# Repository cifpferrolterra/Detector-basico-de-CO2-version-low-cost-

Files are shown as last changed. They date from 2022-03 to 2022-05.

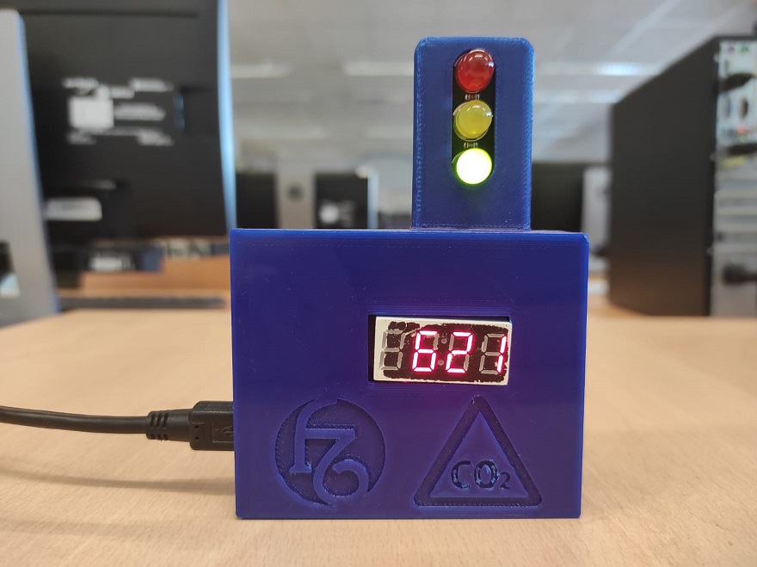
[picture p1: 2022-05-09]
Vista frontal detector low cost.jpg

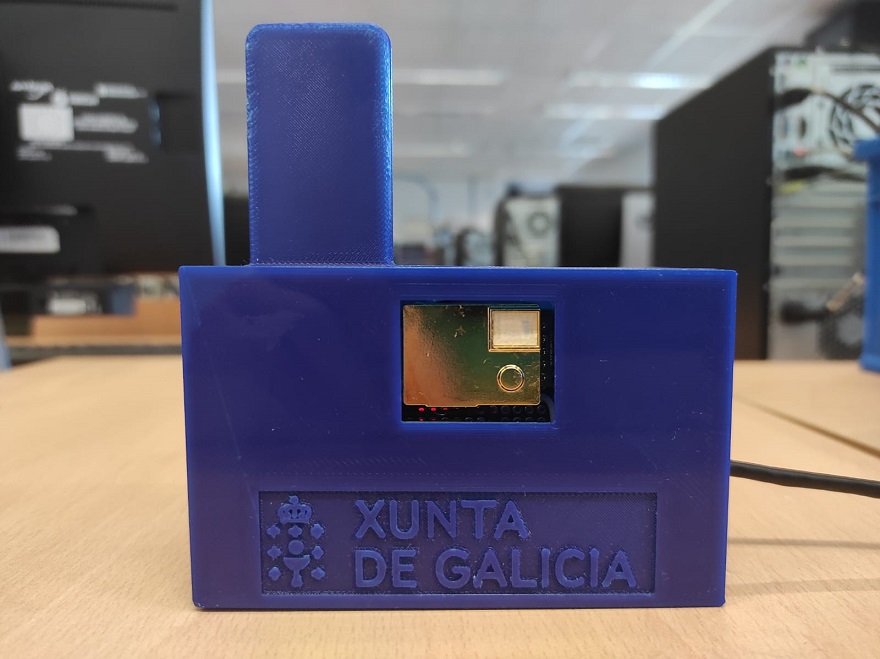
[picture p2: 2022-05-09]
Vista trasera detector low cost.jpg

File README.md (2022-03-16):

# Detector-basico-de-CO2-version-low-cost-
Aulas saudables no CIFP Ferrolterra

A situación de pandemia motivada pola COVID-19 está a xerar a necesidade de ventilar os espazos cunha frecuencia maior do que se facía ata o de agora. Isto débese a que investigadores determinaron que existe unha relación entre os niveis de CO2 e o virus, xa que, se o CO2 está concentrado, o virus estará tamén concentrado exactamente igual, incrementándose a probabilidade de contaxio.
A concentración de CO2 en espazos interiores cerrados aumenta rapidamente na presenza de persoas, que exhalan CO2 ao respirar. A renovación do aire co aire exterior reduce as concentracións de CO2 no interior. Para optimizar esta necesidade de ventilación están a xurdir distintos aparellos de detección de CO2, moitos deles de baixo custo ou low cost. A problemática dalgúns destes últimos é que non fan unha medición real do CO2, senón unha estimación ou prorrateo en función da medición doutros parámetros.
A idea do proxecto “Aulas saudables no CIFP Ferrolterra” xurde da necesidade de ventilación motivada pola pandemia da COVID-19 no noso centro, e da de dispoñer dun sistema de baixo custo que permita contar cunha unidade de detección por aula: ao tratarse dun centro tan grande, unhas 50. A posibilidade de que sexa construíble, programable e reparable no propio centro permitiríanos chegar a telas en menos tempo e cun baixo prezo por unidade. Ademais, no modelo proposto empregarase un sensor de CO2 que nos proporcionará información directa da súa concentración, e non de xeito estimativo a partir de outros parámetros.
Neste caso usarase un sensor de infravermellos MH-Z19 (B ou C) para detectar a concentración de CO2. A información deste sensor será consultada mediante unha placa de Arduino, sendo este Arduino o que mandará a información a tres saídas:
• Pantalla display de 7 segmentos: indicará as partes por millón (en diante ppm) de CO2. Os 7 segmentos permitirán unha visualización a longa distancia, a diferenza de outros tipos, dende distintos puntos da aula.
•	Leds: verde, ≤500 ppm; amarelo, >500 ppm; vermello, >800 ppm.
•	Bocina ou buzzer: que emitirá un sinal sonoro cando se acade o nivel vermello.

Unha vez superada a pandemia a súa utilidade manterase, xa que estes detectores tamén avisarán da nocividade das altas concentracións de CO2 que se xeran en aulas con moito alumnado, mellorando o ambiente na aula. A renovación do aire favorece a atención e o rendemento escolar, xa que a exposición a concentracións de CO2 demasiado elevadas produce aletargamento e dificulta a atención. O RD 1027/2007, RITE, definido en situación de non-pandemia, indica unha ventilación de 12,5 litros por persoa e segundo para aulas de ensino e 20 litros por persoa e segundo para garderías.
Así mesmo, deséxase que este proxecto sirva para a implantación destes detectores nas aulas de outros centros, concibíndoa como o resultado final dun proxecto multidisciplinar. Este detector low cost será facilmente asumible economicamente e autoconstruíble por calquera departamento de tecnoloxía de Galicia que conte cunha impresora 3D para a construción da carcasa. No caso de que o departamento non conte coa impresora 3D poderase adaptar o proxecto cunha caixa plástica ou con características similares. Coa participación do alumnado tentarase espertar neles a súa curiosidade maker e inicialos neste mundo con grande proxección de futuro.
•	En primeiro lugar un modelo básico de detector de CO2 low cost cun display de 7 segmentos no que se mostre a cantidade numérica de CO2 que hai na aula, e tres leds (vermello, amarelo e verde) a modo de semáforo, que indiquen a peligrosidade da concentración en función duns rangos establecidos. Unha emisión sonora avisará de cando a situación obrigue a abrir as fiestras para ventilar. Este sensor medirá valores dende 400 ppm (aire limpo) ata un máximo de 2000-5000 ppm, facendo unha lectura continua (por minuto) que fai que se detecten os incrementos de CO2 que se produzan. No display veranse as ppm de CO2.

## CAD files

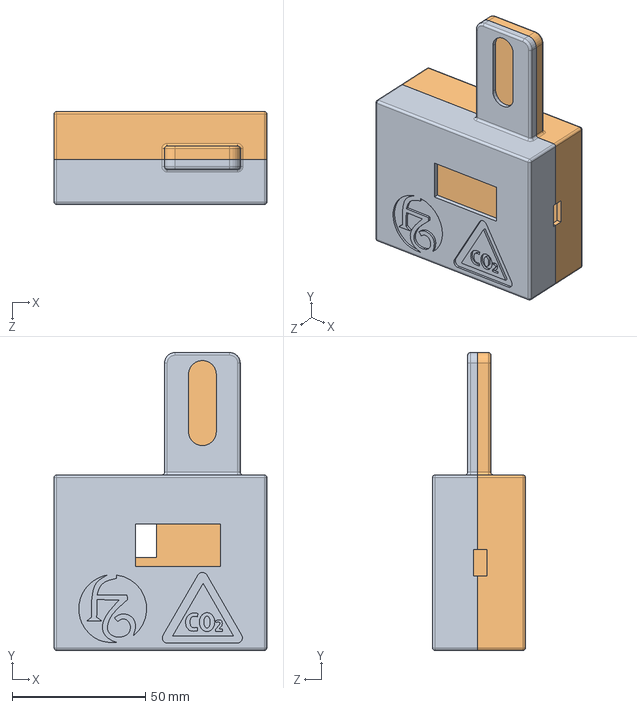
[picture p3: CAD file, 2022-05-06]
modelo1_caixa_sensorCO2/modelo1_caixa_sensorCO2/modelo1_con_logo/modelo1_ensamblaxe_con_logo.SLDASM
80.0 x 112.0 x 35.0 mm
modelo1_caixa1_con_logo
modelo1_caixa2_con_logo

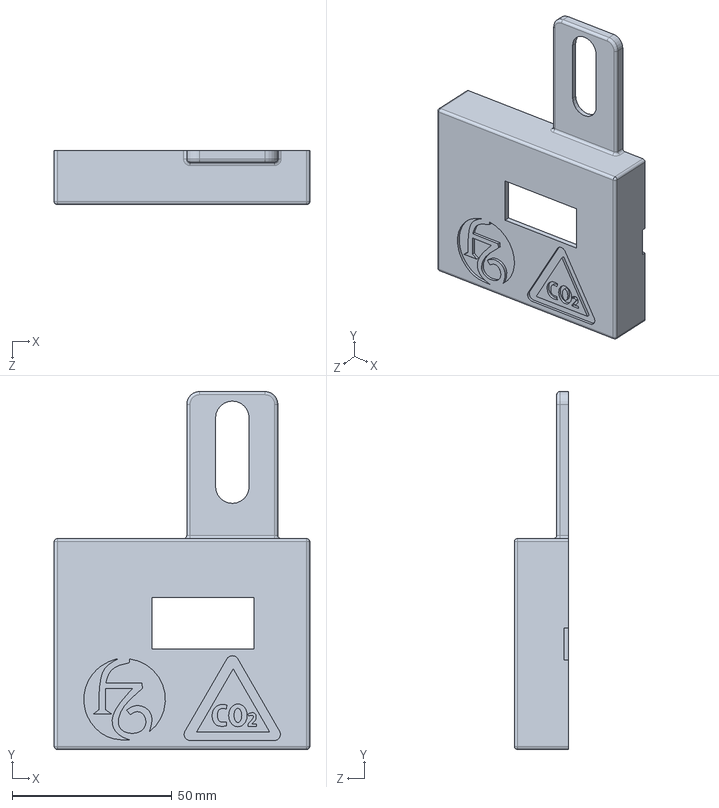
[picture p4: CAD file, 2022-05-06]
modelo1_caixa_sensorCO2/modelo1_caixa_sensorCO2/modelo1_con_logo/modelo1_caixa1_con_logo.SLDPRT
80.0 x 112.0 x 17.0 mm

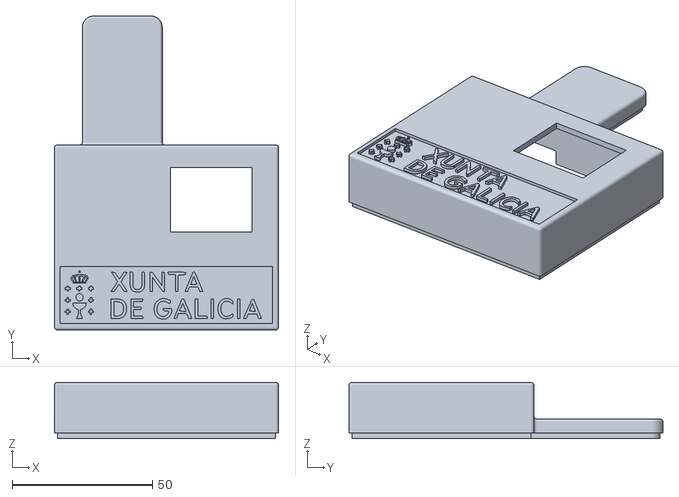
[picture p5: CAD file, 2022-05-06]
modelo1_caixa_sensorCO2/modelo1_caixa_sensorCO2/modelo1_con_logo/modelo1_con_logo_stl/modelo1_caixa2_con_logo.STL
80.0 x 112.0 x 20.0

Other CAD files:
modelo1_caixa_sensorCO2/modelo1_caixa_sensorCO2/modelo1_sen_logo/modelo1_ensamblaxe_sen_logo.SLDASM
modelo1_caixa_sensorCO2/modelo1_caixa_sensorCO2/modelo1_sen_logo/modelo1_caixa2_sen_logo.SLDPRT
modelo1_caixa_sensorCO2/modelo1_caixa_sensorCO2/modelo1_sen_logo/modelo1_sen_logo_stl/modelo1_caixa1_sen_logo.STL
modelo1_caixa_sensorCO2/modelo1_caixa_sensorCO2/modelo1_con_logo/modelo1_caixa2_con_logo.SLDPRT
modelo1_caixa_sensorCO2/modelo1_caixa_sensorCO2/modelo1_con_logo/modelo1_con_logo_stl/modelo1_caixa1_con_logo.STL
modelo1_caixa_sensorCO2/modelo1_caixa_sensorCO2/modelo1_sen_logo/modelo1_caixa1_sen_logo.SLDPRT
modelo1_caixa_sensorCO2/modelo1_caixa_sensorCO2/modelo1_sen_logo/modelo1_sen_logo_stl/modelo1_caixa2_sen_logo.STL
modelo1_caixa_sensorCO2/modelo1_caixa_sensorCO2/modelo1_con_logo.SLDDRW
modelo1_caixa_sensorCO2/modelo1_caixa_sensorCO2/modelo1_con_logo/modelo1_caixa1_con_logo.SLDDRW
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

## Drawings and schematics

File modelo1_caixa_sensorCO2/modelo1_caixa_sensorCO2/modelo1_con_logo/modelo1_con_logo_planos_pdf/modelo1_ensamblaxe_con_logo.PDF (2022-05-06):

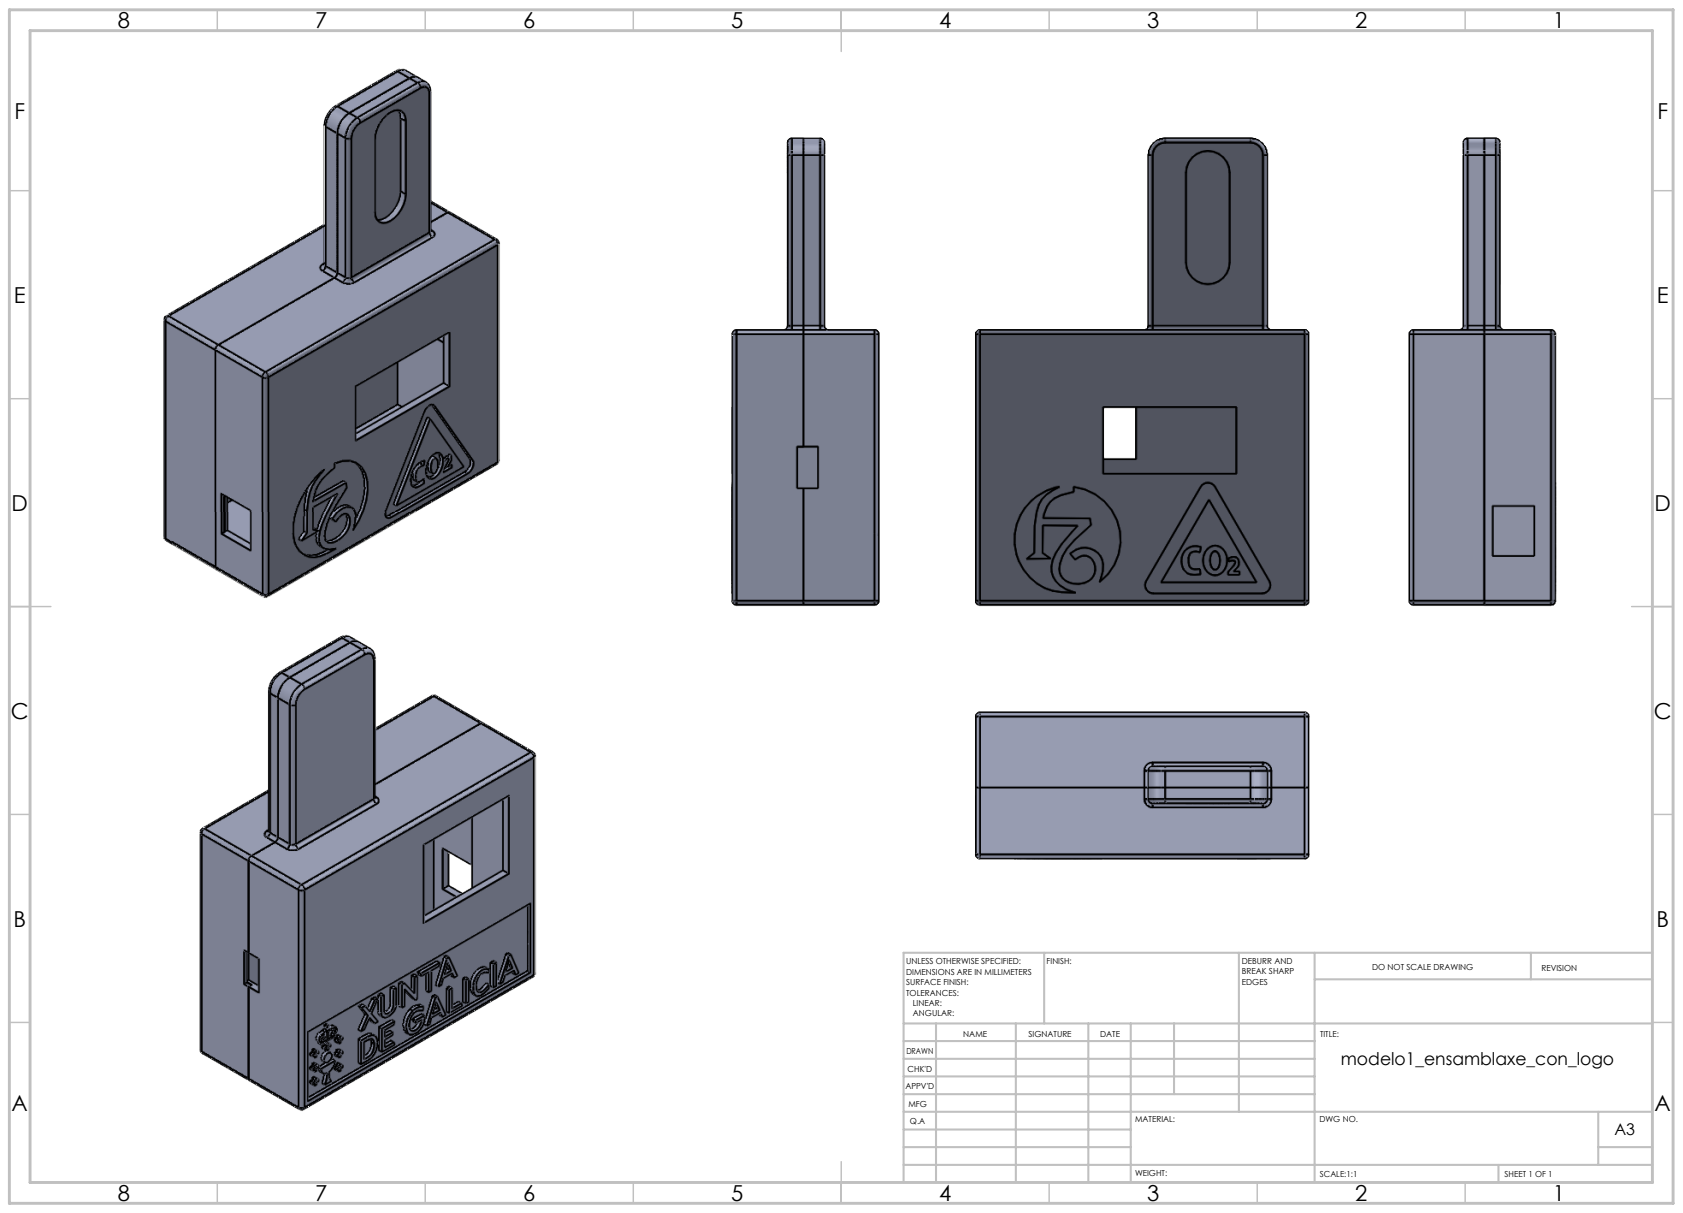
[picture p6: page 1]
FINISH:; DEBURR AND; BREAK SHARP; DO NOT SCALE DRAWING; REVISION; SCALE:1:1; SHEET 1 OF 1

UNLESS OTHERWISE SPECIFIED:
DIMENSIONS ARE IN MILLIMETERS
SURFACE FINISH:
TOLERANCES:
LINEAR:
ANGULAR:

NAME | SIGNATURE | DATE | | | | TITLE: modelo1_ensamblaxe_con_logo

DRAWN
CHK'D
APPV'D
MFG
Q.A | | | | MATERIAL: | DWG NO. | A3

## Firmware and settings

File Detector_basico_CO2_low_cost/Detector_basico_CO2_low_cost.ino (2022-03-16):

/**
 *  Monitor de CO2 para interiores con sensor de (MH-Z19B)
 *  Monitoriza el nivel de CO2 en un espacio cerrado. Primero advierte y luego emite una alarma en caso de que el nivel de CO2 alcance un nivel no aceptable.
 *  La informacion se presenta en una de pantalla de 4 dígitos, una iluminación LED ademas un zumbador avisa al sobrepasar un cierto nivel especifcio.
 *  Su alimentacion será mediante una fuente USB de 5V.
 */
#include <SoftwareSerial.h>                                
#include <MHZ19.h>
#include <TM1637Display.h>
#define RX_PIN 10                                         // pin 10 al Rx pin sensor MHZ19
#define TX_PIN 11                                         // pin 11 al Tx pin sensor MHZ19
#define BAUDRATE 9600                                     // Velocidad en baudios para puerto serie del sensor MH-Z19 (no cambiar)
#define DISPLAY_CLK_PIN 9                                 // Pines de conexión del módulo Display TM1637 (pines digitales CLK = 9 ,DIO = 8)
#define DISPLAY_DIO_PIN 8
#define LED_Verde_pin 6                                   // Pin 6 conexión del LED  color Verde
#define LED_Ama_pin 5                                     // Pin 5 conexión del LED  color Amarillo
#define LED_Rojo_pin 3                                    // Pin 3 conexión del LED  color Rojo
#define T_lectura_sensor 2e3                              // MH-Z19 tiempo entre lecturas del sensor
int int_silen=4;                                          // Pin 4 interruptor de silencio para alarma 
int buzzer=2;                                             // Pin 2 conexión del Buzzer
int ntonos=12;
int tonos[ ]={261,277,294,311,330,349,370,392,415,440,466,494};
boolean valor = false;
boolean estadoalarma = false;
boolean repite = false;




//
//----------------------------------------------------------------------  inicializamos sensor y display -----------------------------------
MHZ19 myMHZ19;                                             
SoftwareSerial mySerial(RX_PIN, TX_PIN);                   
TM1637Display display(DISPLAY_CLK_PIN, DISPLAY_DIO_PIN);
unsigned long Dato_tempo = 0;
int CO2 = 0;
enum LED_COLOR {LED_Rojo, LED_Verde, LED_Ama};

///----------------------------------------------------------------------------------------- configuraciones -----------------------
void setup() {
    Serial.begin(9600);                                    
    mySerial.begin(BAUDRATE);                                
    myMHZ19.begin(mySerial);                             
    myMHZ19.autoCalibration(true);                                 
    pinMode(int_silen,INPUT_PULLUP);
    pinMode(buzzer,OUTPUT);
    display.setBrightness(0x0f);
    }
// ----------------------------------------------------- programa principal --------------------------------------------------------------
void loop() {  if (millis() - Dato_tempo >= T_lectura_sensor)
  {
//--- Obtener la medición de CO2 actual como ppm----------   
    CO2 = myMHZ19.getCO2();         // Solicitar CO2 (como ppm)
    Serial.print("CO2 (ppm): ");                      
    Serial.println(CO2);    
    coloresled();
    valor = digitalRead(int_silen);
    if(valor == true){
    (estadoalarma = 1);
    }else {  
    (estadoalarma = 0);   
    }
    Serial.print("valor int alar: ");
    Serial.println(valor);
    Serial.print("estado alarma act: ");
    Serial.println(estadoalarma); 
    Serial.print("repite ya sono:  ");
    Serial.println(repite);   
    
    display.showNumberDec(CO2,false); 
    Dato_tempo = millis();
  }
   
}
